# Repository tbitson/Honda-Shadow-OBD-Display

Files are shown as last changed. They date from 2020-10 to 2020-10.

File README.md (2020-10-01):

# Honda Shadow OBD Display

This is a 'in-work'n project. Many aspects may not work yet!
 
A Teensy 3.2 based OBD display for a 
2013 Honda Shadow 750 Aero. 

There are 2 parts to this project:
1) A level converter/interface board that connects to the diagnostic connector on the motorcycle. This provides power and opto-isolates the OBD signal. The OBD signal is level shifted to a 3.3V logic level. The schmatic and Eagle PCB files are included.

2) A Teensy 3.2 microcontroller connected to a 240x320 LCD Touchscreen. This displays the various options and OBD values. GThe Teensy and LCD are from PRJC.com. It uses the PCB LCD adapter from PRJC to connect the LCD to the Teensy, and is available from the OSHPark.com.

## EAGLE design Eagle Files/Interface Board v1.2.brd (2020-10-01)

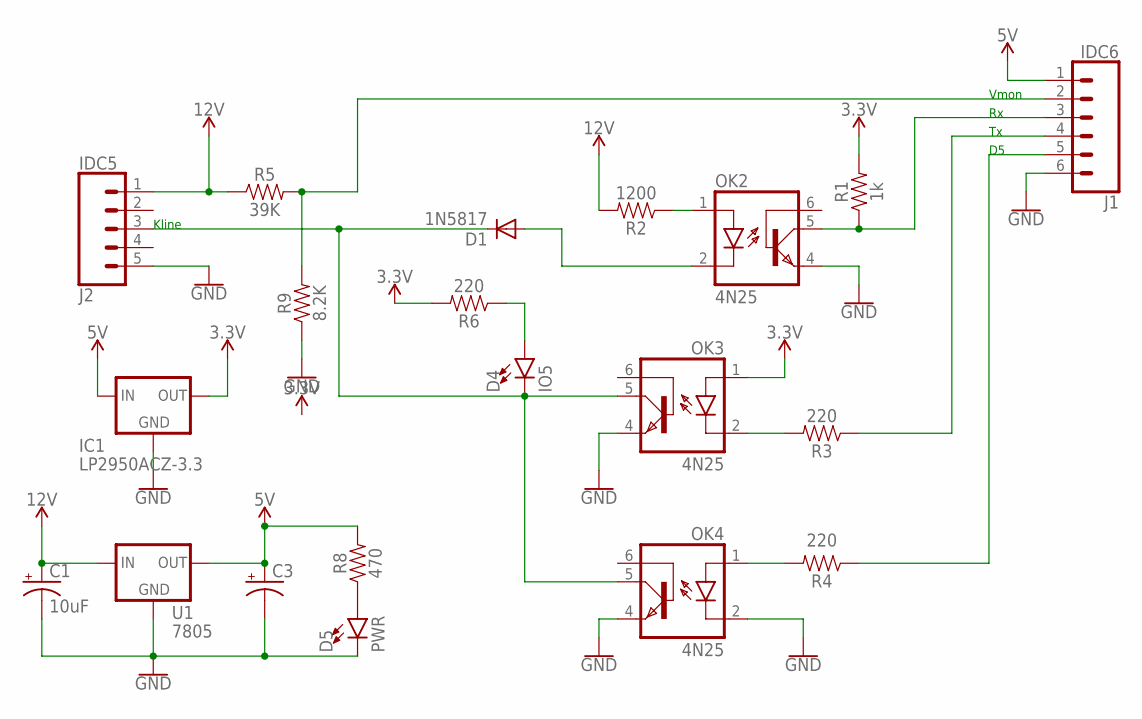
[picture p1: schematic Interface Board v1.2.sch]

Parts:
C1, C3: 10uF; CPOL-RADIAL-2.5MM-5MM
D1: 1N5817; DO41-10
D4: IO5; LED_5MM
D5: PWR; LED_5MM
IC1: LP2950ACZ-3.3; TO92
J1: IDC6; 1X06_LONGPADS
J2: IDC5; 1X05
OK2, OK3, OK4: 4N25; DIL06
R1: 1k; AXIAL-0.3
R2: 1200; AXIAL-0.3
R3, R4, R6: 220; AXIAL-0.3
R5: 39K; AXIAL-0.3
R8: 470; AXIAL-0.3
R9: 8.2K; AXIAL-0.3
U1: 7805; TO-220-ALT

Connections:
3.3V: IC1.1 (OUT), OK3.1 (A), R1.P$2 (2), R6.P$2 (2)
5V: C3.1 (+), IC1.3 (IN), J1.1, R8.P$2 (2), U1.OUT
12V: C1.1 (+), J2.1, R2.P$2 (2), R5.P$1 (1), U1.IN
GND: C1.2 (-), C3.2 (-), D5.K (C), IC1.2 (GND), J1.6, J2.5, OK2.4 (EMI), OK3.4 (EMI), OK4.2 (C), OK4.4 (EMI), R9.P$1 (1), U1.GND
KLINE: D1.C, D4.K (C), J2.3, OK3.5 (COL), OK4.5 (COL)
unnamed: OK3.2 (C), R3.P$2 (2)
unnamed: J1.4, R3.P$1 (1)
unnamed: D1.A, OK2.2 (C)
unnamed: D4.A, R6.P$1 (1)
unnamed: J1.3, OK2.5 (COL), R1.P$1 (1)
unnamed: OK2.1 (A), R2.P$1 (1)
unnamed: D5.A, R8.P$1 (1)
unnamed: J1.5, R4.P$1 (1)
unnamed: OK4.1 (A), R4.P$2 (2)
VMON: J1.2, R5.P$2 (2), R9.P$2 (2)

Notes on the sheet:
Vmon
Kline

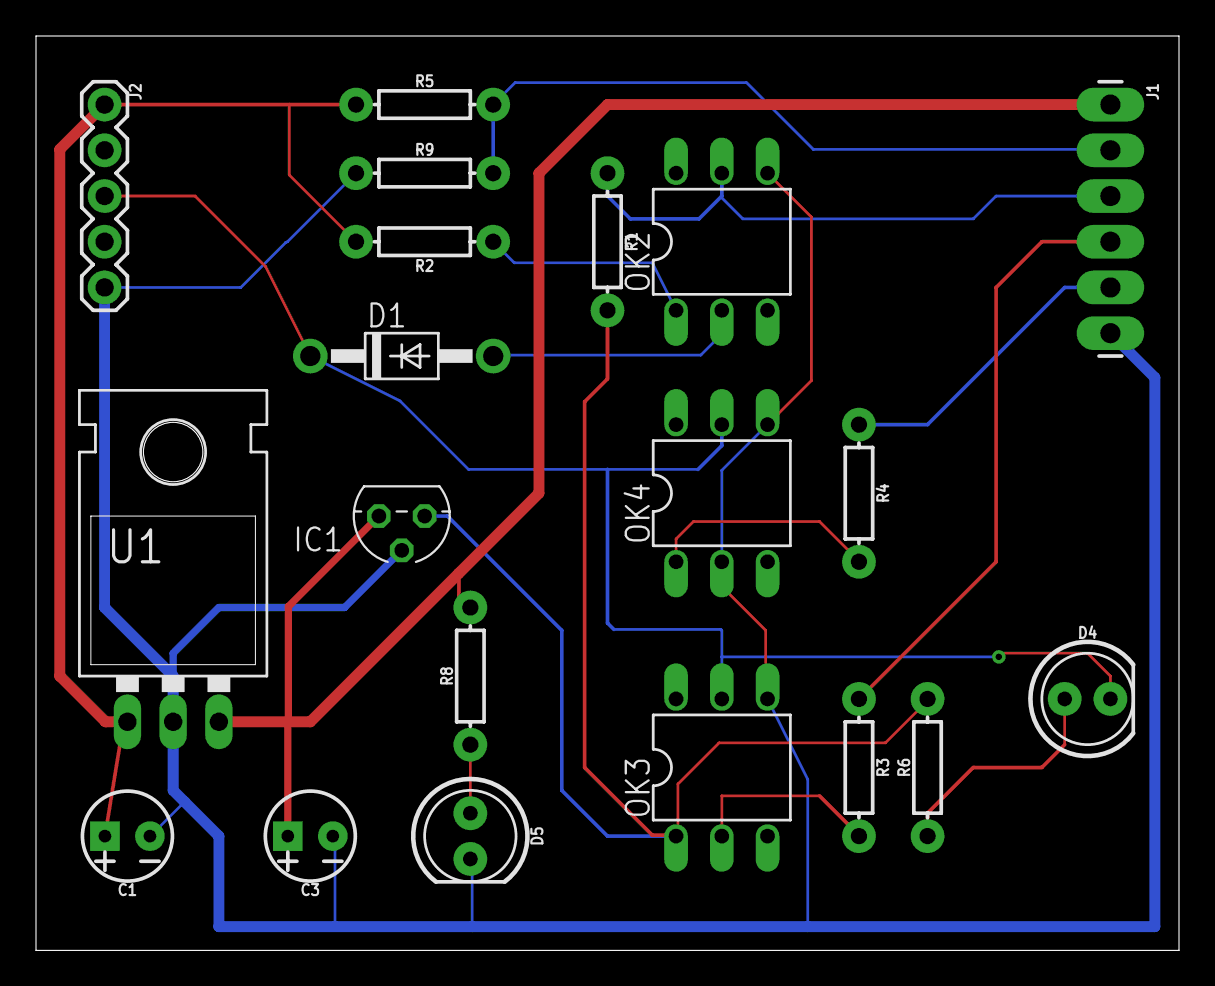
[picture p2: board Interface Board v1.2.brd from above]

Board: 2 copper layers, 63.5 x 50.8 mm, 20 parts (0 on the bottom side), 15 nets.

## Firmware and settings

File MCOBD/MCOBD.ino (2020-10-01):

/*******************3***************************************
  Test tool for development of an OBD interface to
  a 2013 Honda Shadow Aero motorcycle. It uses a
  non-standard K-Line interface at 10400 bps. This
  tool's initial purpose is to test if communication
  can be established between the Teensy and the OBD
  computer.

  Coded for Teensy 3.2

  based on work by gonzo.... Thanks Gonzo!

  Vers 0.10 - Fundamental design, selection of Serial1 port as
              interface to OBD, development of 3 opto-isolator
              design for Rx, Tx, K-line control

  Vers 0.20 - Completed interface testing and initial OBD comunication
              Started dev of data decoding and table design


  Hardware connections:
  WHT - Rx1/D0 - input from Opto-Iso 1 K-line serial data in
  GRN - Tx1/D1 - output to Opto-Iso 2, K-line serial data out
  BLK - D5 - output to Opto-Iso 3, pulls K-line low independant of Tx
  RED - +3.3V to Interface
  UNUSED - A7 - battery voltage thru a resistive divider of 8.2K/39K
  Shield - Ground/Return

  see lcd.h for lcd connections

*********************************************************/

// #define DEBUG_PRINT

#define TITLE_STR "Honda OBD Tool V0.23"


// globals
bool genSerial = false;
bool listenMode = false;
bool simMode = false;

const uint8_t BUFFER_SIZE = 64;
uint8_t rxBuffer[BUFFER_SIZE];
uint8_t txBuffer[BUFFER_SIZE];

// io pins
const int RXD1 = 0;
const int TXD1 = 1;
const int K_LINE = 5;
const int LED = 13;
const int BATT_V = A7;
const int SPARE = 23;


#include "lcd.h"
#include "buttons.h"
//#include "obd.h"
#include "serialCmd.h"





void setup(void)
{
  Serial.begin(57600);
  pinMode(K_LINE, OUTPUT);  // DIO
  digitalWrite(K_LINE, LOW);
  delay(1000);
  Serial.println("Honda MC OBD Tool v 0.22");

  // initalize the lcd display & touchscreen
  lcdInit();

  // draw interface
  int8_t b1 = createButton(20, 40,  "Init Com", OFF, true);
  int8_t b2 = createButton(20, 80,  "Table 1",  OFF, true);
  int8_t b3 = createButton(20, 120, "Table 2",  OFF, true);
  int8_t b4 = createButton(20, 160, "Sim Mode", OFF, true);
  int8_t b5 = createButton(20, 200, "Reset",    OFF, true);

  drawButton(b1);
  drawButton(b2);
  drawButton(b3);
  drawButton(b4);
  drawButton(b5);

  // draw text box
  initTextBox();
}




void loop()
{
  // is button pressed?
  int8_t buttonNum = checkButtons();
  if (buttonNum > 0)
    doButton(buttonNum);
  else
    // is serial command pending
    checkSerialCmd();

  // slow down loop a bit
  delay(100);
}



void doButton(uint8_t buttonNum)
{
  //Serial.print("button = "); Serial.println(buttonNum);

  switch (buttonNum)
  {
    case 1:
      // send init sequence
      updateButton(1, true, true); 
      // init serial port
      openSerial1();
      delay(50);
      initCom();
      textBox("init sent");
      checkDataAvailable(4);
      updateButton(1, false, true);
      break;


    case 2:
      // data table 1
      updateButton(2, true, true);
      Serial.println("requesting table");
      textBox("table 1");
      displayTable11();
      refreshScreen();
      updateButton(2, false, true);
      break;


    case 3:
      updateButton(3, true, true);
      delay(500);
      updateButton(3, false, true);
      break;


    case 4:
      simMode = !simMode;
      updateButton(4, simMode, true);
      delay(1000);
      break;


    case 5:
      updateButton(5, true, true);
      textBox("reset");
      Serial1.end();
      pinMode(RXD1, INPUT);
      pinMode(TXD1, INPUT);
      pinMode(K_LINE, OUTPUT);
      digitalWrite(K_LINE, LOW);
      Serial.println("reset complete");
      delay(1000);
      textBox("done");
      updateButton(5, false, true);
      break;
  }
}






float readBatteryVolts()
{
  // resistor divider scaled to 19V for 1023 counts
  float v = (float)analogRead(BATT_V) * 19.0 / 1023.0;
  printValue("Battery Volts", v);
  return v;
}


void testIO(bool useTextBox)
{
  // test IO
  Serial1.end();
  pinMode(RXD1, OUTPUT);     // serial1 Rx
  pinMode(TXD1, OUTPUT);     // serial1 Tx
  pinMode(K_LINE, OUTPUT);  // DIO

  if (useTextBox) textBox("Setting Rx High");
  digitalWrite(RXD1, HIGH);
  delay(2000);
  if (useTextBox) textBox("Setting Rx Low");
  digitalWrite(RXD1, LOW);
  delay(1000);

  if (useTextBox) textBox("Setting Tx High");
  digitalWrite(TXD1, HIGH);
  delay(2000);
  if (useTextBox) textBox("Setting TX Low");
  digitalWrite(TXD1, LOW);
  delay(1000);

  if (useTextBox) textBox("Setting K-line High");
  digitalWrite(K_LINE, HIGH);
  delay(2000);
  if (useTextBox) textBox("Setting K-line Low");
  digitalWrite(K_LINE, LOW);
  delay(1000);

  // restore serial config
  pinMode(RXD1, INPUT);     // serial1 Rx
  pinMode(TXD1, INPUT);     // serial1 Tx
  Serial1.begin(BAUD);
}

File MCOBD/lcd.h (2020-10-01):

/*************************************************
   lcd.h - initialization stuff for demo-ing buttons
   using an TFT LCD display on teensy. See the demo
   code from the Teensyduino library for details.

   Version 1.1

 ***************************************************/


#ifndef LCD_H
#define LCD_H


#include <Wire.h>
#include "ILI9341_t3.h"
#include <XPT2046_Touchscreen.h>
#include <font_Arial.h>
#include <font_ArialBold.h>

#define TEENSY_32

// This is calibration data for the raw touch data to the screen coordinates
#define TS_MINX 150
#define TS_MINY 130
#define TS_MAXX 3800
#define TS_MAXY 4000


// lcd interface
#define TFT_DC    9   // Serial 2 Rx
#define TFT_CS    10  // Serial 2 Tx
#define TFT_RST   255 // (unused, tie to +3.3)
#define TFT_SDI   11  // SPI DOUT  
#define TFT_SCK   13  // SPI SCLK
#define TFT_SDO   12  // SPI DIN


#define TS_CS_PIN  8  // Serial 3 Tx
#define TS_IRQ_PIN 2  // DIO


// ref lcd size
#define LCD_WIDTH   320
#define LCD_HEIGHT  240

// textbox on main screen
#define TB_POS_X  150
#define TB_POS_Y  40
#define TB_WIDTH  160
#define TB_HEIGHT 200

#define CURSOR_Y_HOME   45
#define CURSOR_X_HOME   155
#define CURSOR_LIMIT_X  300
#define CURSOR_LIMIT_Y  190


// include buttons after defines
#include "buttons.h"


// globals
ILI9341_t3 lcd = ILI9341_t3(TFT_CS, TFT_DC, TFT_RST, TFT_SDI, TFT_SCK, TFT_SDO);
XPT2046_Touchscreen ts(TS_CS_PIN);
uint16_t cursorX;
uint16_t cursorY;


void lcdInit()
{
  lcd.begin();
  lcd.setRotation(3);
  lcd.fillScreen(ILI9341_BLACK);
  delay(1000);

  printValue("LCD Width ", lcd.width());
  printValue("LCD Height", lcd.height());

  ts.begin();
  ts.setRotation(1);

  lcd.fillScreen(ILI9341_BLACK);
  lcd.setTextColor(ILI9341_WHITE);
  lcd.setFont(Arial_14_Bold);
  lcd.setCursor(40, 0);
  lcd.print(TITLE_STR);
}



void refreshScreen()
{
  lcd.fillScreen(ILI9341_BLACK);
  lcd.setTextColor(ILI9341_WHITE);
  lcd.setFont(Arial_14_Bold);
  lcd.setCursor(40, 0);
  lcd.print(TITLE_STR);
  drawAllButtons();
  lcd.drawRoundRect(TB_POS_X, TB_POS_Y, TB_WIDTH, TB_HEIGHT, 4, ILI9341_RED);
}


void initTextBox()
{
  lcd.fillRoundRect(TB_POS_X, TB_POS_Y, TB_WIDTH, TB_HEIGHT, 4, ILI9341_BLACK);
  lcd.drawRoundRect(TB_POS_X, TB_POS_Y, TB_WIDTH, TB_HEIGHT, 4, ILI9341_RED);

  cursorX = CURSOR_X_HOME;
  cursorY = CURSOR_Y_HOME;
}


void textBox(String msg)
{
  // if at the bottom, erase and start over
  if (cursorY > CURSOR_LIMIT_Y)
    initTextBox();

  lcd.setTextColor(ILI9341_WHITE);
  lcd.setFont(Arial_8);
  lcd.setCursor(cursorX, cursorY);
  lcd.print(msg);
  //Serial.println(msg);
  cursorY += 12;
}


void textBoxHex(byte val)
{
  // if at the bottom, erase and start over
  if (cursorY > CURSOR_LIMIT_Y)
    initTextBox();

  lcd.setTextColor(ILI9341_WHITE);
  lcd.setFont(Arial_8);
  lcd.setCursor(cursorX, cursorY);
  lcd.print("0x");
  if (val < 0x10)
    lcd.print("0");
  lcd.print(val, HEX);
  cursorX += 32;
  if (cursorX > CURSOR_LIMIT_X)
  {
    cursorX = CURSOR_X_HOME;
    cursorY += 12;
  }
}


/*
   ILI9341 library reference

   ILI9341_t3(uint8_t _CS, uint8_t _DC, uint8_t _RST = 255, uint8_t _MOSI=11, uint8_t _SCLK=13, uint8_t _MISO=12);
   void begin(void);
   void sleep(bool enable);
   void pushColor(uint16_t color);
   void fillScreen(uint16_t color);
   void drawPixel(int16_t x, int16_t y, uint16_t color);
   void drawFastVLine(int16_t x, int16_t y, int16_t h, uint16_t color);
   void drawFastHLine(int16_t x, int16_t y, int16_t w, uint16_t color);
   void fillRect(int16_t x, int16_t y, int16_t w, int16_t h, uint16_t color);
   void fillRectHGradient(int16_t x, int16_t y, int16_t w, int16_t h, uint16_t color1, uint16_t color2);
   void fillRectVGradient(int16_t x, int16_t y, int16_t w, int16_t h, uint16_t color1, uint16_t color2);
   void fillScreenVGradient(uint16_t color1, uint16_t color2);
   void fillScreenHGradient(uint16_t color1, uint16_t color2);
   void setRotation(uint8_t r);
   void setScroll(uint16_t offset);
   void invertDisplay(boolean i);
   void setAddrWindow(uint16_t x0, uint16_t y0, uint16_t x1, uint16_t y1);

   adafruit GFX library
   void drawCircle(int16_t x0, int16_t y0, int16_t r, uint16_t color);
   void drawCircleHelper(int16_t x0, int16_t y0, int16_t r, uint8_t cornername, uint16_t color);
   void fillCircle(int16_t x0, int16_t y0, int16_t r, uint16_t color);
   void fillCircleHelper(int16_t x0, int16_t y0, int16_t r, uint8_t cornername, int16_t delta, uint16_t color);
   void drawTriangle(int16_t x0, int16_t y0, int16_t x1, int16_t y1, int16_t x2, int16_t y2, uint16_t color);
   void fillTriangle(int16_t x0, int16_t y0, int16_t x1, int16_t y1, int16_t x2, int16_t y2, uint16_t color);
   void drawRoundRect(int16_t x0, int16_t y0, int16_t w, int16_t h, int16_t radius, uint16_t color);
   void fillRoundRect(int16_t x0, int16_t y0, int16_t w, int16_t h, int16_t radius, uint16_t color);
   void drawBitmap(int16_t x, int16_t y, const uint8_t *bitmap, int16_t w, int16_t h, uint16_t color);
   void drawChar(int16_t x, int16_t y, unsigned char c, uint16_t color, uint16_t bg, uint8_t size);
   void setCursor(int16_t x, int16_t y);
   void getCursor(int16_t *x, int16_t *y);
   void setTextColor(uint16_t c);
   void setTextColor(uint16_t c, uint16_t bg);
   void setTextSize(uint8_t s);
   uint8_t getTextSize();
   void setTextWrap(boolean w);
   boolean getTextWrap();
   virtual size_t write(uint8_t);
   int16_t width(void)  { return _width; }
   int16_t height(void) { return _height; }
   uint8_t getRotation(void);
   void drawLine(int16_t x0, int16_t y0, int16_t x1, int16_t y1, uint16_t color);
   void drawRect(int16_t x, int16_t y, int16_t w, int16_t h, uint16_t color);
   int16_t getCursorX(void) const { return cursor_x; }
   int16_t getCursorY(void) const { return cursor_y; }
   void setFont(const ILI9341_t3_font_t &f) { font = &f; }
   void setFontAdafruit(void) { font = NULL; }
   void drawFontChar(unsigned int c);
   void measureChar(uint8_t c, uint16_t* w, uint16_t* h);
   uint16_t fontCapHeight() { return (font) ? font->cap_height : textsize * 8; }
   uint16_t fontLineSpace() { return (font) ? font->line_space : textsize * 8; }
   uint16_t fontGap() { return (font) ? font->line_space - font->cap_height : 0; };
   uint16_t measureTextWidth(const char* text, int chars = 0);
   uint16_t measureTextHeight(const char* text, int chars = 0);
   int16_t strPixelLen(char * str);
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

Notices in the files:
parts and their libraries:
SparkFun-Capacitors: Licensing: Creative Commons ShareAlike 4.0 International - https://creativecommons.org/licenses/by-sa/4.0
